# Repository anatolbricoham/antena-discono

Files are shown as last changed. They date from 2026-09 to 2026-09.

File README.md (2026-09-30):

# Antena discono casera 80–1300 MHz

Construye una discono de banda ancha para escáner o SDR por unos 25–40 €, con varilla de aluminio, dos bujes torneados y piezas imprimibles en 3D.

Medidas

| | |
|---|---|
| Cobertura | 80 a más de 1000 MHz (FM, aviación, marina, AIS, DAB+, UHF) |
| Polarización | Vertical, omnidireccional, 0–2 dBi |
| Tamaño | Cono Ø94 cm × 81 cm, disco Ø66 cm |
| Materiales | ≈10 m de varilla Ø4 mm, barra de aluminio Ø40 y Ø50, conector N |
| Nivel | Bricolaje básico, una tarde |

## Contenido

```
GUIA.md               Guía completa: medidas, materiales, paso a paso, ajuste e instalación
calcular_discono.py   Calculadora de medidas para cualquier frecuencia mínima
3d/
  discono_3d.scad     Piezas paramétricas (OpenSCAD)
  stl/                9 piezas listas para imprimir
  LEEME.txt           Material, orientación y uso de cada pieza
img/                  Dibujo acotado y vista de las piezas
```

## Empezar

1. Lee la [guía](GUIA.md).
2. ¿Otra frecuencia mínima? `python3 calcular_discono.py 50`
3. Imprime las piezas de [`3d/stl`](3d/stl) en PETG o ASA; para otras medidas edita los parámetros de `discono_3d.scad` y exporta con OpenSCAD:
   ```bash
   openscad -D 'PART="spacer"' -o spacer.stl 3d/discono_3d.scad
   ```

## Aviso

Las medidas se basan en las proporciones clásicas de la discono y son un punto de partida: compruébalas con un analizador (NanoVNA) antes de instalarla. Instala siempre descargador y toma de tierra.

## Comunidad

Proyecto compartido en [BricoHams · Radioafición, hazlo tú mismo](https://t.me/bricohams). Mejoras, fotos de montajes y medidas reales son bienvenidas mediante issues o pull requests.

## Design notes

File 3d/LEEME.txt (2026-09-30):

PIEZAS IMPRIMIBLES 3D - DISCONO CASERA 80-1300 MHz 
=========================================================================

Material: PETG o ASA (van al exterior; el PLA se deforma con el sol).
Ajustes generales: capa 0,2 mm, 4 perímetros, 5 capas arriba/abajo, relleno 40 %.
Todas las medidas se cambian en discono_3d.scad (OpenSCAD) y se re-exportan.

PIEZA              TAMAÑO (mm)        UDS  RELLENO  ORIENTACIÓN / NOTAS
spacer.stl         Ø40 x 12            1   100 %    Plano. Aislante entre disco y cono (tornillos de NAILON M4).
jig_cono.stl       Ø60 x 24            1    40 %    Cara con texto sobre la cama. Plantilla de taladrado del buje Ø40.
jig_disco.stl      Ø70 x 22            1    40 %    Cara con texto sobre la cama. Plantilla de taladrado del buje Ø50.
galga30.stl        90 x 150 x 10       1    20 %    Plano. Galga para doblar las varillas del cono a 30°.
anillo.stl         Ø194 x 10           1    40 %    Plano. Necesita cama de 200 x 200 mm o más.
tapa_disco.stl     Ø55 x 18            1    40 %    Cara cerrada sobre la cama. Tapa antilluvia del buje del disco.
puntas.stl         16 x Ø9 x 14,5     16    40 %    Cúpula hacia arriba. Protegen las puntas de las varillas.
acople.stl         Ø44 x 38            1    60 %    Cara con los agujeros grandes hacia arriba. Une buje del cono y tubo Ø32.
tapon.stl          Ø36 x 18            1    40 %    Ala sobre la cama. Tapón inferior del tubo con paso del coaxial y drenaje.

CÓMO SE USAN
1. jig_cono / jig_disco: encaja la plantilla sobre la barra de aluminio (la cara superior de la
   barra toca el techo de la plantilla). Sujeta ambas en el tornillo de banco y taladra:
   - por los 8 agujeros laterales con broca de 4,2 mm (agujeros radiales de las varillas),
   - por los 8 agujeros de arriba con broca de 3,3 mm (luego roscar M4 para los prisioneros),
   - por el central (cono 6 mm / disco 3,3 mm).
   La marca lateral indica dónde va el agujero nº 1. Taladra despacio: el plástico solo guía.
2. spacer: sustituye al taco de PVC. Imprímelo al 100 % para que no se aplaste.
3. galga30: apoya el lado largo con tope en el tubo y dobla cada varilla hasta que toque la galga.
4. anillo: se coloca unos 10 cm por debajo del buje del cono (donde las varillas forman Ø180 mm).
   Cada varilla entra a presión por su ranura; asegúrala con una brida fina por el agujero lateral.
   Da rigidez y mantiene las 8 varillas a 45°. El plástico no afecta a la antena.
5. tapa_disco: se pega con silicona neutra sobre el buje del disco; las ranuras dejan pasar las varillas.
6. puntas: se pegan con una gota de silicona o cianoacrilato en las 16 puntas.
7. acople: el tubo Ø32 entra por abajo (fijar con 2 tornillos M4 laterales); arriba se atornilla
   al buje del cono con 2 M4 a 16 mm del centro (taladrar y roscar esos 2 agujeros en el buje,
   separados de los 4 del conector). El conector N y la clavija quedan dentro del hueco de Ø21.
8. tapon: cierra el tubo por abajo; el coaxial sale por el agujero central (coax_d = 8 mm por defecto;
   cámbialo a 5 para RG-58/H-155 o a 10,5 para RG-213).

Parámetros clave en el .scad: rod_d (varilla), tube_od / tube_id (tubo), coax_d, ring_r, cone_angle.

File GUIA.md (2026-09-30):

# Guía de construcción: antena discono casera 80–1300 MHz

Una discono de 8 + 8 varillas cubre de 80 a más de 1000 MHz con una sola bajada, por unos 25–40 € de materiales (una comercial tipo Diamond D-130J cuesta unos 140 €).

- **Usos típicos:** escáner y SDR en FM 87,5–108, aviación 118–137, VHF marina 156–162 y AIS, DAB+ 174–240 y UHF.
- **Polarización:** vertical. **Ganancia:** 0–2 dBi, omnidireccional.
- **Tiempo:** una tarde (3–4 h). **Nivel:** bricolaje básico, sin soldar aluminio.

Las medidas salen de las proporciones clásicas de la discono (Kandoian). Son de partida: la sección de comprobación explica cómo verificarlas.

Medidas de la discono

El disco (arriba) va al vivo del coaxial; el cono y el mástil van a la malla, separados del disco solo por el aislante.

## 1. Medidas (frecuencia mínima 80 MHz)

| Pieza | Medida teórica | Medida de corte |
|---|---|---|
| Varilla del cono (×8), desde el vértice | 94 cm | 95 cm (1,2 cm entran en el buje; se recorta después) |
| Ángulo de cada varilla respecto al mástil | 30° (cono de 60°) | — |
| Diámetro de la boca del cono | 94 cm | — |
| Altura del cono | 81 cm | — |
| Varilla del disco (×8), desde el centro | 33 cm | 32 cm con buje de 50 mm (30,5 libres + 1,5 dentro) |
| Diámetro del disco | 66 cm | — |
| Buje del cono (arriba) | Ø40 mm | barra de aluminio de 25 mm de alto |
| Separación disco–cono | 12 mm | 12 mm (0,3 × 40 mm) |
| Separación angular entre varillas | 45° | 45° |

**Para otra frecuencia mínima** usa `python3 calcular_discono.py <MHz>`, o las fórmulas:

- Varilla del cono (cm) = 7500 ÷ frecuencia mínima (MHz)
- Diámetro del disco = 0,7 × varilla del cono (con cono de 60°)
- Separación disco–cono = 0,3 × diámetro del buje del cono

| Frecuencia mínima | Varilla del cono | Diámetro del disco | Uso |
|---|---|---|---|
| 50 MHz | 150 cm | 105 cm | Añade la banda de 6 m; más grande y pesada |
| 70 MHz | 107 cm | 75 cm | Margen extra por debajo de la FM |
| **80 MHz** | **94 cm** | **66 cm** | **Equilibrio tamaño/cobertura (recomendada)** |
| 100 MHz | 75 cm | 53 cm | Aviación, marina y UHF; la FM entra peor |

Por encima de unas 12 veces la frecuencia mínima el diagrama se levanta y la antena rinde menos en el horizonte.

## 2. Materiales

Precios orientativos, no consultados.

| # | Material | Cantidad | Detalle | Precio aprox. |
|---|---|---|---|---|
| 1 | Varilla de aluminio maciza Ø4–5 mm | 8 × 95 cm + 8 × 32 cm (≈10 m) | Varilla de soldadura TIG de aluminio o de latón | 10–15 € |
| 2 | Buje del cono | 1 | Barra redonda de aluminio Ø40 mm, trozo de 25 mm | 3–5 € |
| 3 | Buje del disco | 1 | Barra redonda de aluminio Ø50 mm, trozo de 12 mm | 3 € |
| 4 | Separador aislante | 1 | Taco de PVC/nailon/teflón Ø40 × 12 mm, o la pieza 3D `spacer` | 2 € |
| 5 | Conector hembra de chasis | 1 | N (mejor, estanco) o SO-239, con brida de 4 tornillos | 4–8 € |
| 6 | Hilo de cobre rígido | 5 cm | 1,5–2,5 mm² | — |
| 7 | Tubo soporte | 1 | PVC o aluminio Ø25–32 mm, 50–80 cm | 3–6 € |
| 8 | Prisioneros M4 inox | 16 | Fijan cada varilla en su buje | 3 € |
| 9 | Tornillos de nailon M4 + tuercas | 2 | Unen disco, aislante y cono (metálicos harían cortocircuito) | 1 € |
| 10 | Abrazaderas en U inox | 2 | Tubo al mástil | 4 € |
| 11 | Coaxial de bajas pérdidas | según bajada | H-155 o RG-213 si pasa de 10 m | 1–2 €/m |
| 12 | Conector macho | 1 | N o PL-259 | 3–5 € |
| 13 | Autovulcanizante + silicona neutra | 1 + 1 | Estanqueidad | 6 € |
| 14 | Grasa dieléctrica | 1 | Contra la corrosión entre metales | 4 € |
| 15 | Tapón de PVC | 1 | Tapa el buje del disco (o la pieza 3D `tapa_disco`) | 1 € |

## 3. Herramientas

- Taladro (mejor de columna) y brocas de 2,5 / 3,3 / 4,2 / 6 mm
- Macho de roscar M4 con maneral
- Sierra de metal y lima
- Transportador o la galga 3D de 30°
- Calibre y cinta métrica, tornillo de banco, llaves
- Soldador de estaño 40–60 W
- Opcional: analizador NanoVNA

## 4. Construcción paso a paso

### A. Cortar las varillas

1. Endereza la varilla rodándola sobre una mesa plana.
2. Corta **8 varillas de 95 cm** (cono) y **8 de 32 cm** (disco).
3. Lima las puntas y achaflana el extremo que entra en el buje.
4. Marca la profundidad de inserción: 12 mm en las del cono, 15 mm en las del disco.

### B. Buje del disco (Ø50 × 12 mm)

1. Marca el centro y 8 radios a 45° (o usa la plantilla 3D `jig_disco`).
2. Taladra en el canto **8 agujeros radiales de 4,2 mm**, 15 mm de profundidad, a media altura.
3. Encima de cada uno, desde la cara superior, taladra a 3,3 mm y rosca **M4** para el prisionero.
4. Taladra el centro a 3,3 mm y rosca M4 para el hilo del conector.

### C. Buje del cono (Ø40 × 25 mm)

1. Taladra el eje de lado a lado a **6 mm** (por ahí sube el vivo).
2. En la cara inferior, centra la brida del conector, marca y rosca sus 4 agujeros.
3. Amplía el centro de la cara inferior para que entre el cuerpo del conector y la brida apoye plana.
4. En el canto, a 8 mm de la cara superior, taladra **8 agujeros radiales de 4,2 mm** a 45°, 12 mm de profundidad (o usa `jig_cono`).
5. Encima de cada agujero, rosca M4 para su prisionero.

### D. Separador aislante (Ø40 × 12 mm)

1. Taladra el centro a 6 mm.
2. Taladra 2 agujeros de 4,2 mm a 12 mm del centro, enfrentados, para los **tornillos de nailon**.
3. Repite esos 2 agujeros en ambos bujes, roscando M4 en el del cono.

### E. Conector y vivo

1. Atornilla el conector por debajo del buje del cono (la malla queda unida al cono).
2. Suelda al pin central un hilo de cobre rígido de 5 cm.
3. Pásalo por el centro del cono y del separador **sin que toque el aluminio** (aíslalo con dieléctrico de coaxial).
4. Coloca separador y disco, y únelos al cono con los 2 tornillos de nailon.
5. Haz un ojal en el hilo y atorníllalo al centro del disco. El tramo debe ser recto y corto.
6. Polímetro: **vivo–disco = continuidad**, **malla–cono = continuidad**, **disco–cono = abierto**.

### F. Varillas

1. Mete las 8 del disco hasta la marca y aprieta los prisioneros: horizontales y a 45°.
2. Mete las 8 del cono hasta la marca y aprieta.
3. Dobla cada varilla del cono **a 1 cm del buje**, con radio suave, hasta **30° con el eje** (galga `galga30`).
4. Comprueba: puntas en un círculo de **94 cm** y unos **81 cm** por debajo del buje.
5. Iguala las puntas recortando las largas.

### G. Tubo soporte

1. Fija el buje del cono en lo alto del tubo (o con la pieza 3D `acople`).
2. Pasa el coaxial por dentro y conéctalo antes de cerrar.
3. Deja un bucle de goteo a la salida del tubo.

## 5. Piezas imprimibles en 3D

Carpeta [`3d/`](3d/): archivo OpenSCAD paramétrico, 9 STL y [LEEME](3d/LEEME.txt). Imprimir en **PETG o ASA** (exterior).

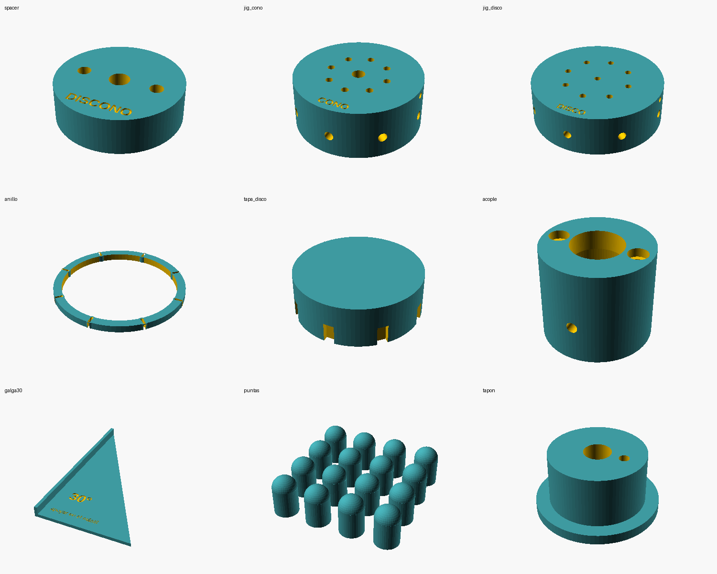
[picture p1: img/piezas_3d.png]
Piezas 3D


| Pieza | Tamaño | Uds | Para qué |
|---|---|---|---|
| spacer | Ø40 × 12 mm | 1 | Aislante disco–cono (relleno 100 %) |
| jig_cono | Ø60 × 24 mm | 1 | Plantilla de taladrado del buje Ø40 |
| jig_disco | Ø70 × 22 mm | 1 | Plantilla de taladrado del buje Ø50 |
| galga30 | 90 × 150 mm | 1 | Doblar las varillas del cono a 30° |
| anillo | Ø194 × 10 mm | 1 | Separador del cono, ~10 cm bajo el buje (cama ≥ 200 × 200) |
| tapa_disco | Ø55 × 18 mm | 1 | Tapa antilluvia del buje del disco |
| puntas | Ø9 × 14,5 mm | 16 | Protectores de las puntas |
| acople | Ø44 × 38 mm | 1 | Buje del cono → tubo Ø32 con el conector dentro |
| tapon | Ø36 × 18 mm | 1 | Tapón inferior con paso del coaxial y drenaje |

Los bujes siguen siendo de aluminio porque llevan la RF. Mide tu conector N antes de imprimir el `acople` (hueco de 21 mm).

## 6. Estanqueidad y corrosión

1. Grasa dieléctrica en prisioneros y contactos entre metales distintos.
2. Silicona **neutra** (no ácida) alrededor del hilo central en el separador.
3. Tapa el buje del disco con la cazoleta o `tapa_disco`.
4. Autovulcanizante en los conectores, estirada un 50 % y solapada; encima cinta aislante contra el sol.
5. Agujero de drenaje de 2 mm en la parte baja del tubo.

## 7. Comprobación y ajuste

Objetivo: ROE < 2:1 desde ~85 MHz hasta pasado 1 GHz, medida en exterior.

**Con NanoVNA:** calibra (open/short/load) al final del cable, barre 50–1300 MHz y:

- ROE alta en todo el rango → revisa la separación disco–cono (prueba 8–15 mm) y el vivo.
- Mala solo por debajo de 90–100 MHz → varillas del cono cortas o cono muy abierto (ciérralo a 25°).
- Picos sueltos en UHF → alguna varilla distinta en longitud o ángulo.

**Sin analizador:** compara con la antena anterior los niveles de canal 16 (156,800), AIS (161,975), una torre de aeropuerto cercana y una FM débil, o cuenta los barcos AIS recibidos en una hora.

## 8. Instalación

1. Tubo al mástil con dos abrazaderas en U, el disco por encima de la punta del mástil.
2. Al menos 1–2 m de separación con otras antenas.
3. Coaxial pegado al mástil con bridas cada 50 cm y bucle de goteo.
4. Descargador coaxial a la entrada unido a la toma de tierra (16 mm²).
5. Si la FM se cuela en aviación en tu SDR, baja la ganancia.

## 9. Problemas frecuentes

| Síntoma | Causa probable | Solución |
|---|---|---|
| No se recibe nada | Vivo tocando el cono o hilo suelto | Disco–cono debe dar abierto; rehaz el hilo |
| Peor que la antena anterior en VHF baja | Varillas del cono cortas o cono muy abierto | Cierra a 25–30° o alarga |
| FM en la banda de aviación | Saturación del receptor | Baja la ganancia |
| Ruido de fondo alto | Routers, LED, cargadores cerca | Sube y aleja la antena |
| Cambia con la lluvia | Agua en conector o buje | Seca, sella, drena |
| Varillas torcidas por el viento | Prisioneros flojos o varilla fina | Fijador de roscas; varilla de 5 mm; `anillo` 3D |

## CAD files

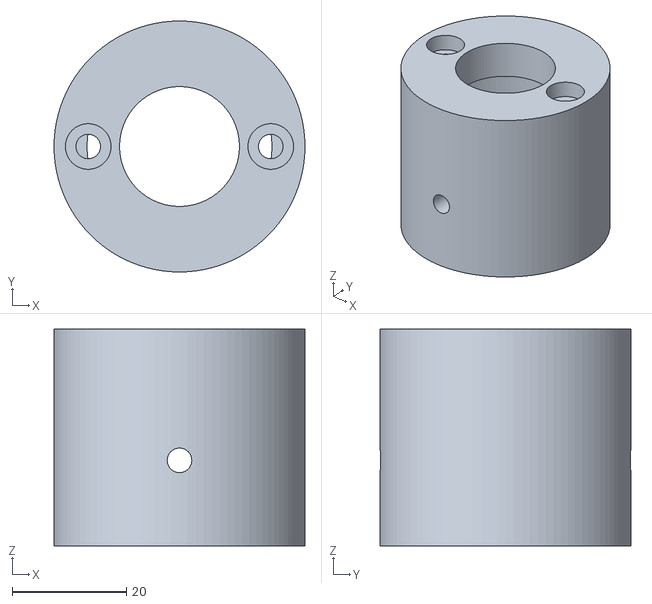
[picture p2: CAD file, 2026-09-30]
3d/stl/acople.stl
44.0 x 44.0 x 38.0

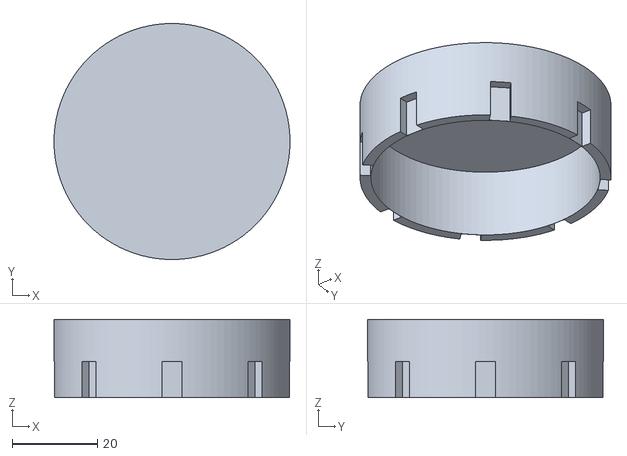
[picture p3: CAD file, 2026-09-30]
3d/stl/tapa_disco.stl
55.4 x 55.4 x 18.4

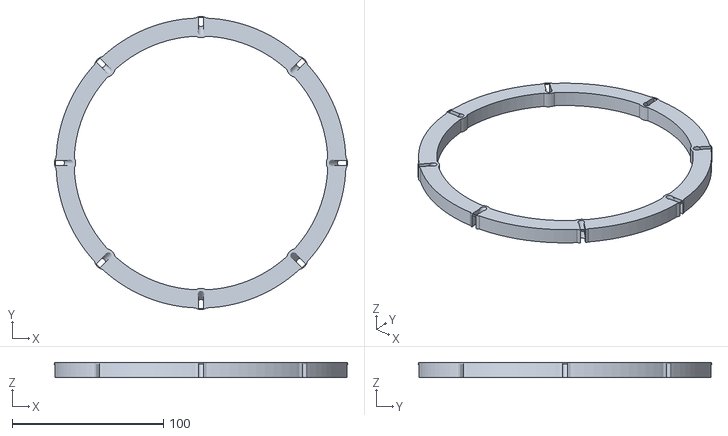
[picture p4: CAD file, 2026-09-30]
3d/stl/anillo.stl
194.0 x 194.0 x 10.0

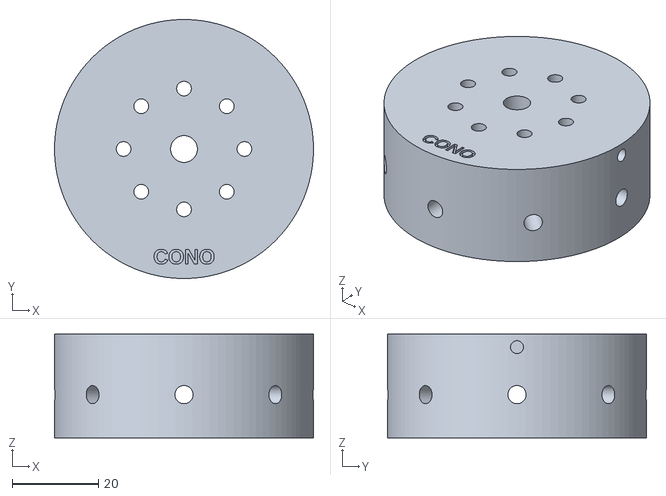
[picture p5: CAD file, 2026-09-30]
3d/stl/jig_cono.stl
60.0 x 60.0 x 24.0

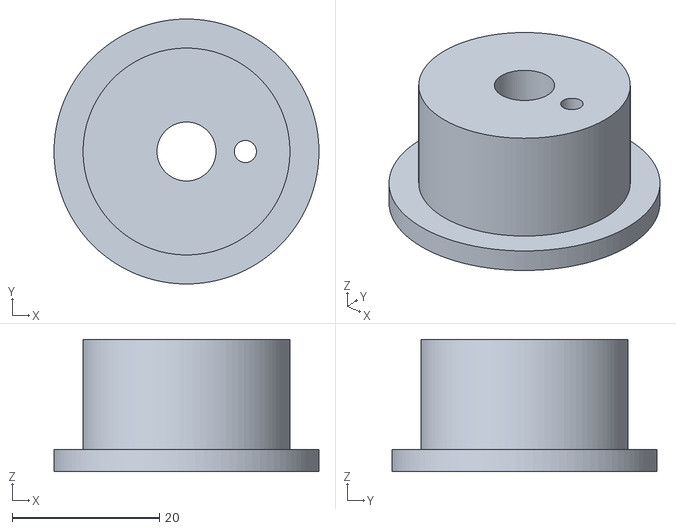
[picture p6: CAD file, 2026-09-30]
3d/stl/tapon.stl
36.0 x 36.0 x 18.0

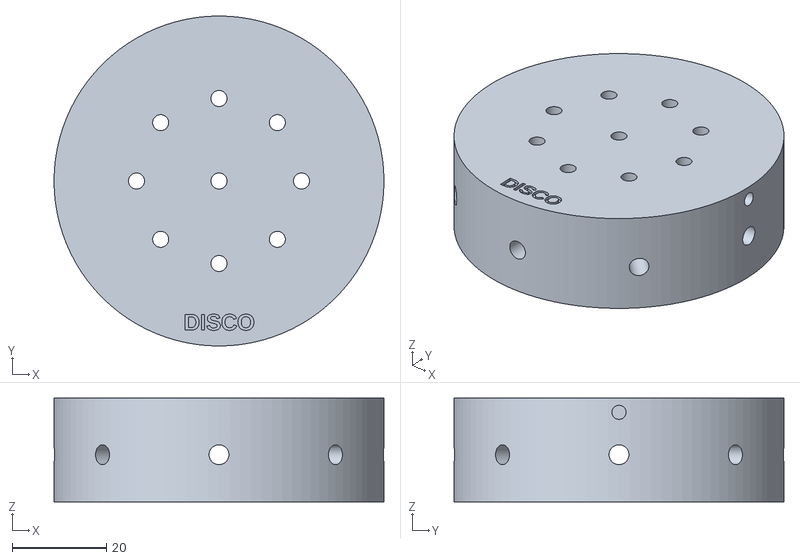
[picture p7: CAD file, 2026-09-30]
3d/stl/jig_disco.stl
70.0 x 70.0 x 22.0

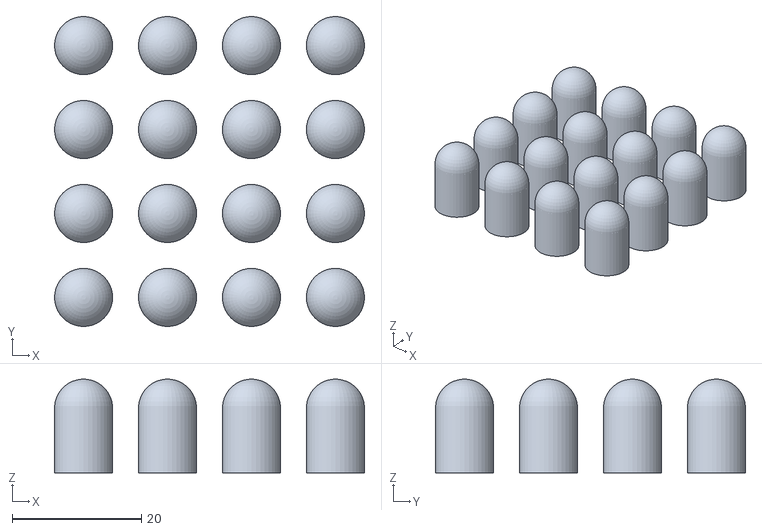
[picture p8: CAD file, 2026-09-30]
3d/stl/puntas.stl
48.0 x 48.0 x 14.5

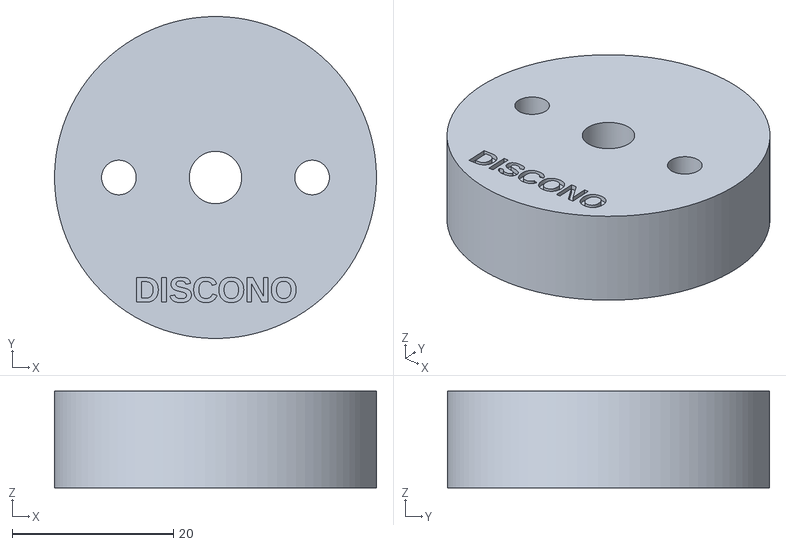
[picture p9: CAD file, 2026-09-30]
3d/stl/spacer.stl
40.0 x 40.0 x 12.0

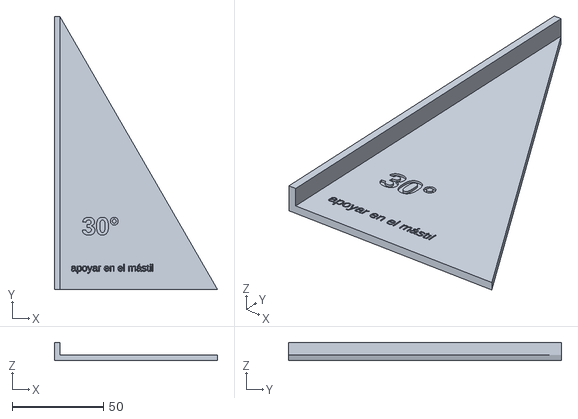
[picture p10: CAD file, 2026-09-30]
3d/stl/galga30.stl
89.6 x 150.0 x 10.0

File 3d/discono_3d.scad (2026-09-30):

// =====================================================================
//  Piezas imprimibles 3D para la discono casera 80-1300 MHz
//  Paramétrico (OpenSCAD). Elige la pieza con PART y exporta a STL.
//  Material recomendado: PETG o ASA (exterior, resistente UV)
// =====================================================================
PART = "todas";   // spacer | jig_cono | jig_disco | galga30 | anillo | tapa_disco | puntas | acople | tapon | todas

etiqueta = "DISCONO";  // texto grabado en el aislante

// ---------- Medidas de la antena (coinciden con la guía) ----------
rod_d        = 4.0;    // varilla de aluminio
rod_clear    = 0.35;   // holgura de impresión para la varilla
cone_hub_d   = 40;     // buje del cono (barra de aluminio Ø40)
cone_hub_h   = 25;
cone_hole_z  = 8;      // centro de los agujeros radiales, medido desde la cara superior
cone_hole_depth = 12;
disc_hub_d   = 50;     // buje del disco (barra de aluminio Ø50)
disc_hub_h   = 12;
disc_hole_depth = 15;
gap          = 12;     // separación disco-cono = grosor del aislante
bolt_r       = 12;     // tornillos de nailon M4 del aislante
tube_od      = 32;     // tubo soporte (PVC o aluminio)
tube_id      = 28.4;   // interior del tubo
coax_d       = 8;      // paso del coaxial en el tapón (RG-58 5, H-155 5.4, RG-213 10.3)
ring_r       = 90;     // radio del anillo separador (centro de las varillas)
cone_angle   = 30;     // ángulo de las varillas del cono respecto al eje
tol          = 0.4;    // holgura general de encaje
$fn = 96;

// ---------- utilidades ----------
module radial_holes(n, r0, z, d, len) {
    for (i = [0:n-1]) rotate([0,0,i*360/n])
        translate([r0, 0, z]) rotate([0,90,0]) cylinder(d=d, h=len, center=true);
}
module txt(s, size=5, h=0.8) { linear_extrude(h) text(s, size=size, halign="center", valign="center", font="Liberation Sans:style=Bold"); }

// 1) Separador aislante Ø40 x 12 (sustituye al taco de PVC/nailon). Imprimir al 100 %.
module spacer() {
    difference() {
        union() {
            cylinder(d=cone_hub_d, h=gap);
            // labio de centrado que encaja en el buje del disco (rebaje opcional)
        }
        translate([0,0,-1]) cylinder(d=6.5, h=gap+2);                 // vivo del coaxial
        for (s=[-1,1]) translate([s*bolt_r,0,-1]) cylinder(d=4.3, h=gap+2); // tornillos nailon M4
        translate([0, -14, gap-0.6]) txt(etiqueta, 3.2, 1);
    }
}

// 2) y 3) Plantillas de taladrado: se encajan sobre la barra de aluminio y guían
//    los 8 agujeros radiales (4,2 mm), los 8 de los prisioneros (3,3 mm) y el central.
module drill_jig(bar_d, hole_z, hole_depth, center_d, label) {
    wall = 10; top = 6; skirt = hole_z + 10;
    pr = bar_d/2 - hole_depth/2;          // radio de los prisioneros
    difference() {
        cylinder(d=bar_d + 2*wall, h=skirt + top);
        translate([0,0,-1]) cylinder(d=bar_d + tol, h=skirt + 1);          // encaje en la barra
        // agujeros radiales guía (centro a hole_z por debajo de la cara superior de la barra)
        radial_holes(8, bar_d/2 + wall/2, skirt - hole_z, 4.2, wall + 2);
        // guías verticales de los prisioneros M4 (broca 3,3)
        for (i=[0:7]) rotate([0,0,i*45]) translate([pr,0,skirt-1]) cylinder(d=3.4, h=top+2);
        // guía central
        translate([0,0,skirt-1]) cylinder(d=center_d, h=top+2);
        // marca de orientación
        translate([bar_d/2 + wall - 1.5, 0, skirt + top/2]) rotate([0,90,0]) cylinder(d=3, h=3, center=true);
        translate([0, -(bar_d/2 + 5), skirt + top - 0.6]) txt(label, 3.5, 1);
    }
}

// 4) Galga de 30°: se apoya en el mástil para doblar las 8 varillas del cono igual.
module galga30() {
    L = 150;
    difference() {
        linear_extrude(3) polygon([[0,0],[0,L],[L*tan(cone_angle),0]]);
        translate([12, 30, 2.2]) linear_extrude(1) text("30°", size=10, font="Liberation Sans:style=Bold");
        translate([6, 10, 2.2]) linear_extrude(1) text("apoyar en el mástil", size=4);
    }
    // tope que abraza el tubo/mástil
    translate([-3,0,0]) cube([3, L, 10]);
}

// 5) Anillo separador del cono: mantiene las 8 varillas a 45° y a 30°.
//    Las varillas entran a presión por una ranura exterior; brida opcional.
module anillo() {
    boss = 14; th = 10;
    difference() {
        union() {
            difference() { cylinder(r=ring_r + 6, h=th); translate([0,0,-1]) cylinder(r=ring_r - 6, h=th+2); }
            for (i=[0:7]) rotate([0,0,i*45]) translate([ring_r,0,0]) cylinder(d=boss, h=th);
        }
        for (i=[0:7]) rotate([0,0,i*45]) translate([ring_r,0,th/2]) {
            rotate([0,-cone_angle,0]) cylinder(d=rod_d + rod_clear, h=40, center=true);    // agujero inclinado
            rotate([0,-cone_angle,0]) translate([4,0,0]) cube([8, rod_d*0.85, 40], center=true); // ranura de clipado
            translate([0, 0, 0]) rotate([90,0,0]) translate([-4.5,0,0]) cylinder(d=3.2, h=boss+2, center=true); // brida
        }
    }
}

// 6) Tapa antilluvia del buje del disco (Ø50 x 12) con 8 ranuras para las varillas.
module tapa_disco() {
    wall = 2.4; inner_h = disc_hub_h + 4; id = disc_hub_d + tol + 0.2;
    difference() {
        cylinder(d=id + 2*wall, h=inner_h + wall);
        translate([0,0,-1]) cylinder(d=id, h=inner_h + 1);
        // ranuras desde el borde abierto hasta el centro de la varilla + radio
        for (i=[0:7]) rotate([0,0,i*45]) translate([id/2, 0, -1])
            translate([0,-(rod_d+0.6)/2,0]) cube([wall+2, rod_d+0.6, disc_hub_h/2 + rod_d/2 + 1.5]);
    }
}

// 7) Puntas protectoras de las varillas (16 uds): evitan pinchazos y el agua dentro.
module punta() {
    $fn = 40;
    difference() {
        union() { cylinder(d=9, h=10); translate([0,0,10]) sphere(d=9); }
        translate([0,0,-1]) cylinder(d=rod_d + rod_clear, h=11);
    }
}
module puntas() { for (x=[0:3], y=[0:3]) translate([x*13, y*13, 0]) punta(); }

// 8) Acople buje del cono -> tubo soporte Ø32 (el conector N queda dentro).
module acople() {
    h_sock = 30; plate = 8; d = tube_od + 2*6;
    difference() {
        cylinder(d=d, h=h_sock + plate);
        translate([0,0,-1]) cylinder(d=tube_od + tol, h=h_sock + 1);                // encaje del tubo
        translate([0,0,h_sock-1]) cylinder(d=21, h=plate+2);                        // cuerpo del conector y clavija
        for (a=[0,180]) rotate([0,0,a]) translate([16,0,h_sock-1]) cylinder(d=4.3, h=plate+2);   // M4 al buje
        for (a=[0,180]) rotate([0,0,a]) translate([16,0,h_sock+plate-3.5]) cylinder(d=8, h=4);   // alojamiento cabeza
        for (a=[90,270]) rotate([0,0,a]) translate([0,0,h_sock/2]) rotate([0,90,0]) cylinder(d=4.3, h=d, center=false); // tornillos al tubo
    }
}

// 9) Tapón inferior del tubo con paso del coaxial y drenaje.
module tapon() {
    difference() {
        union() { cylinder(d=tube_id - 0.3, h=15); translate([0,0,-3]) cylinder(d=tube_od + 4, h=3); }
        translate([0,0,-5]) cylinder(d=coax_d, h=25);
        translate([8,0,-5]) cylinder(d=3, h=25);    // drenaje
    }
}

// ---------- selector ----------
if (PART == "spacer")     spacer();
if (PART == "jig_cono")   drill_jig(cone_hub_d, cone_hole_z, cone_hole_depth, 6.2, "CONO");
if (PART == "jig_disco")  drill_jig(disc_hub_d, disc_hub_h/2, disc_hole_depth, 3.4, "DISCO");
if (PART == "galga30")    galga30();
if (PART == "anillo")     anillo();
if (PART == "tapa_disco") tapa_disco();
if (PART == "puntas")     puntas();
if (PART == "acople")     acople();
if (PART == "tapon")      tapon();
if (PART == "todas") {
    translate([0,0,0])      spacer();
    translate([70,0,0])     drill_jig(cone_hub_d, cone_hole_z, cone_hole_depth, 6.2, "CONO");
    translate([155,0,0])    drill_jig(disc_hub_d, disc_hub_h/2, disc_hole_depth, 3.4, "DISCO");
    translate([0,70,0])     tapa_disco();
    translate([70,70,0])    acople();
    translate([140,60,3])   tapon();
    translate([180,50,0])   puntas();
    translate([0,140,0])    galga30();
    translate([200,300,0])  anillo();
}
